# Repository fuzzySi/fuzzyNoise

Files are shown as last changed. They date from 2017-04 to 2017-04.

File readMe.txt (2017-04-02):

# fuzzyNoise

noise source, and sample and hold module for modular synth
designed by fuzzySynths. made by and for musicians. open source. 

Designs for a modular synth module. This fits in to a standard eurorack modular synth, running on the usual +12v/gnd/-12v rails. A reversed transistor in breakdown generates white noise, which is also filtered to pink noise. These are available as outputs, but the white noise, or an external source, feeds a sample and hold module to generate a CV signal, changing with every incoming gate signal. An internal LFO clocks this if there is no external gate, and is available as a separate out. Pots control LFO rate, and CV glide (portamento, ie the time between changes of voltage). 

Schematics are done in KiCad.

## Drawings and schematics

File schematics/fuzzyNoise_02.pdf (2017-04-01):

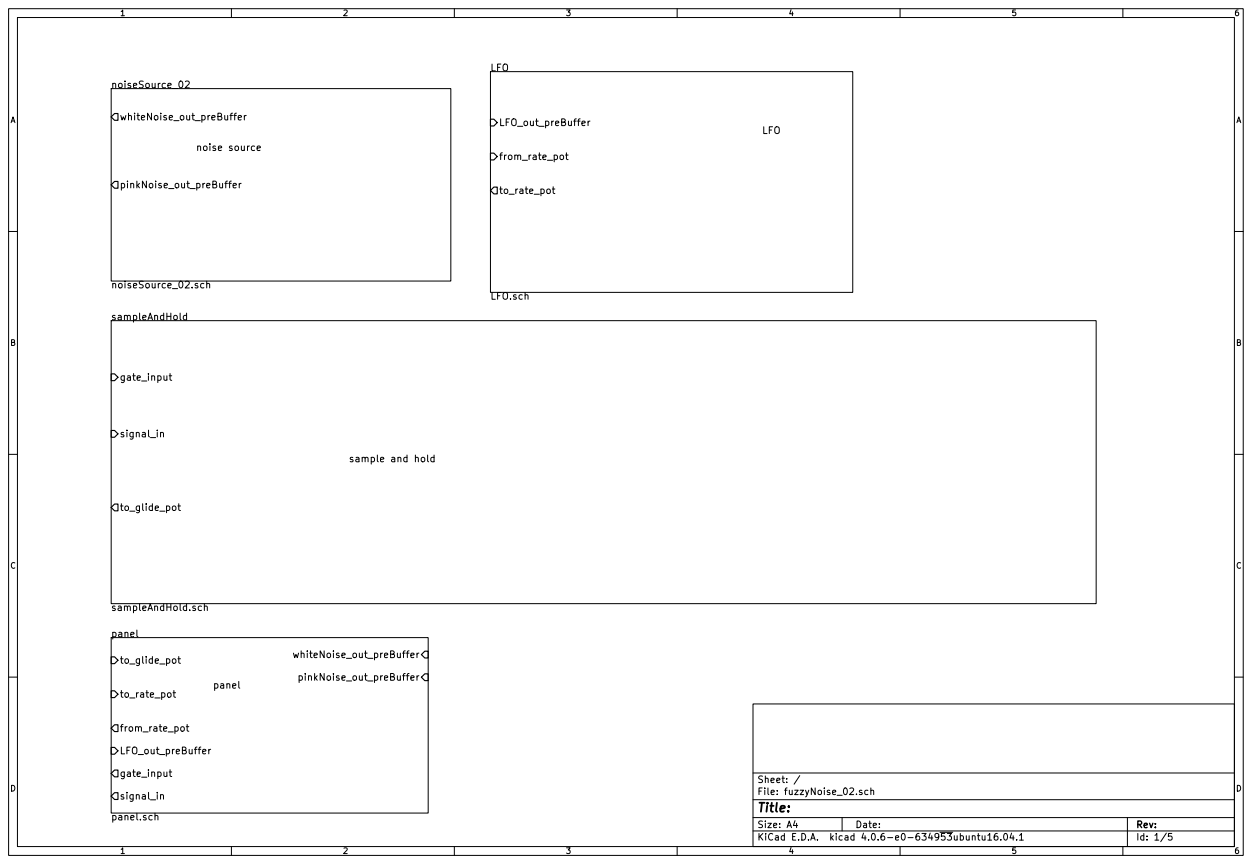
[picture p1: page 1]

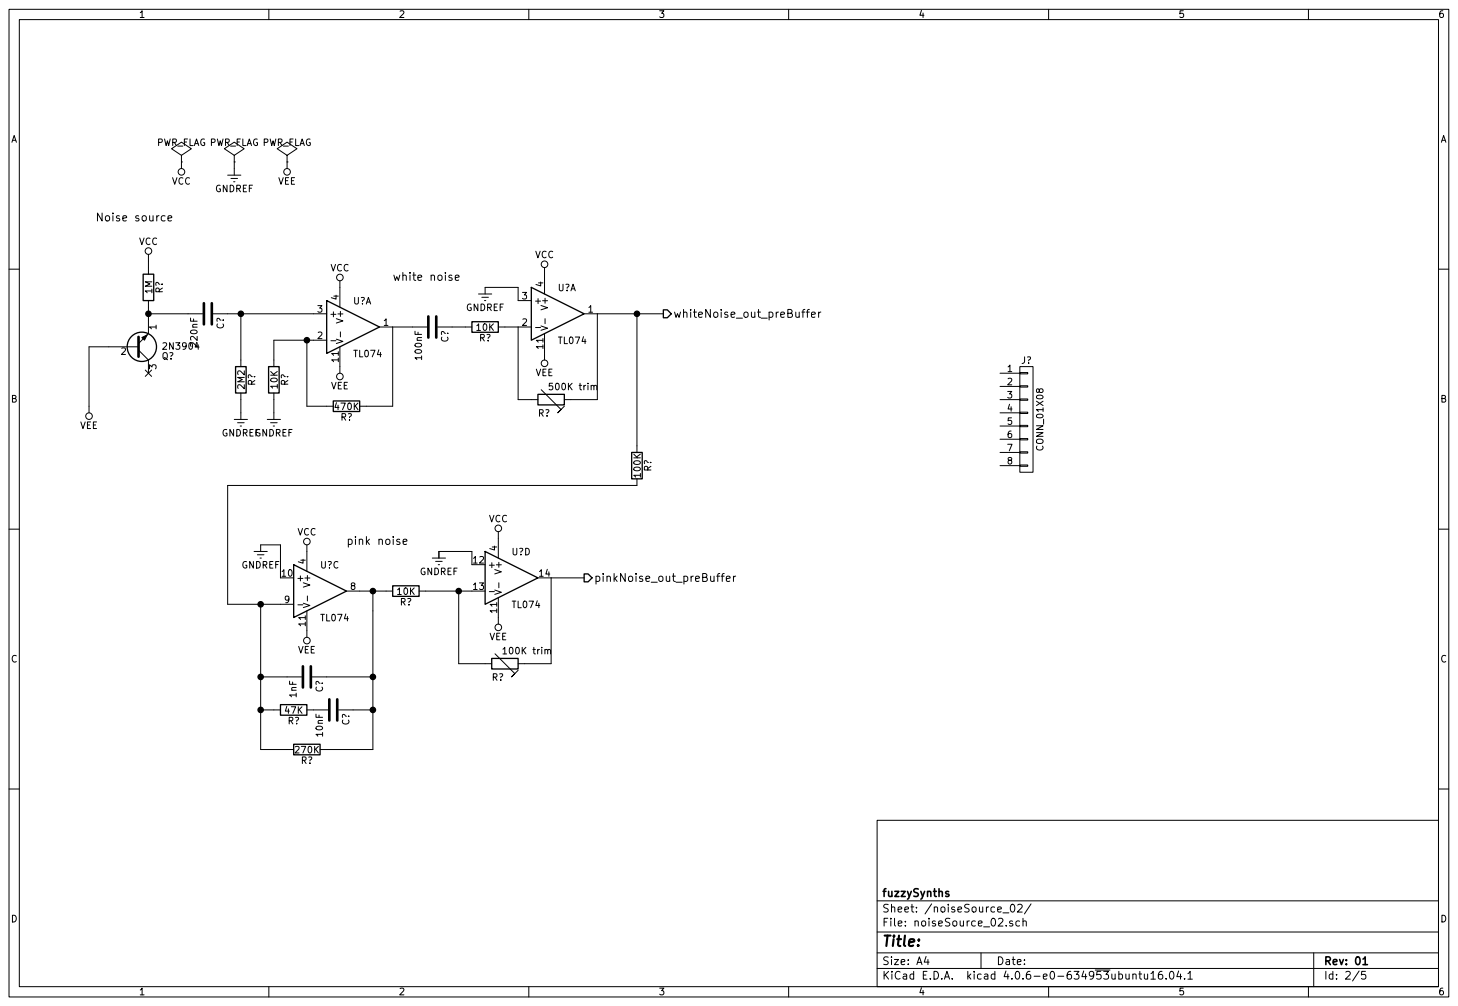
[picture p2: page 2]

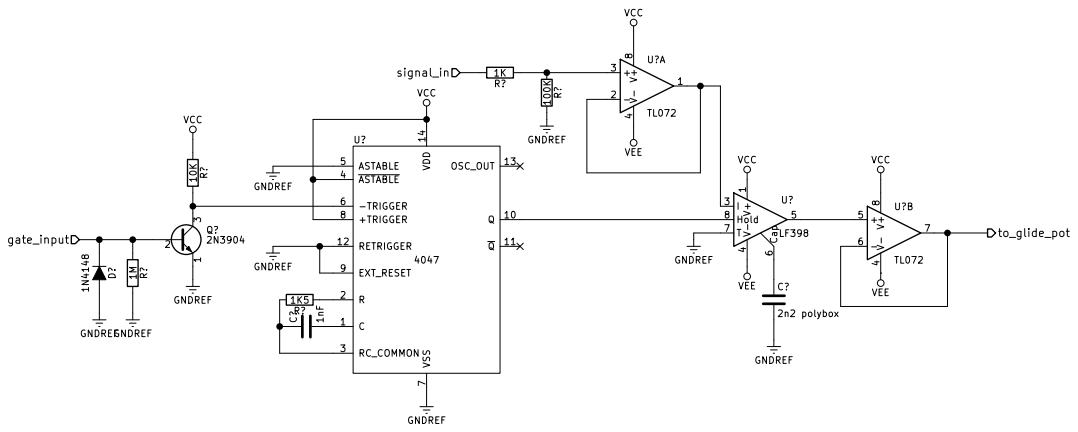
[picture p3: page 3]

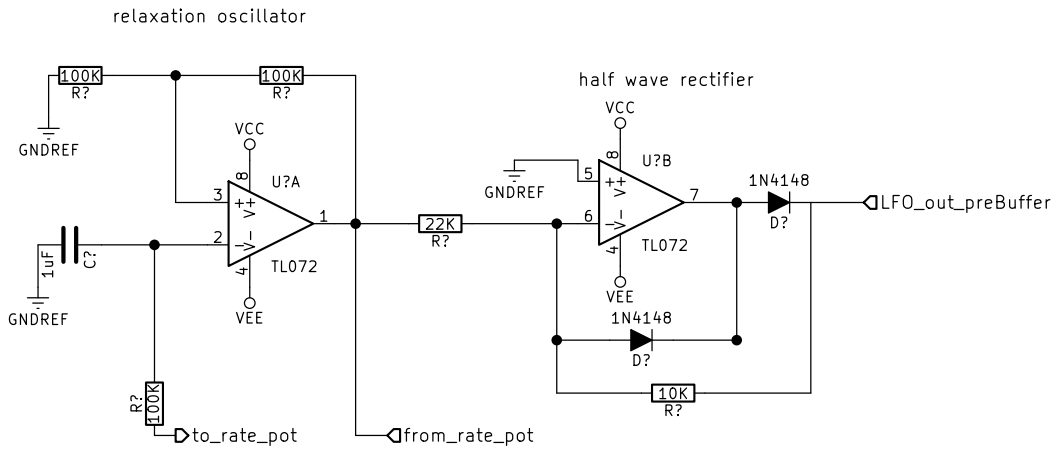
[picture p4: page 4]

Id: 4/5 Title: File: LFO.sch Sheet: /LFO/ V- 4 V+

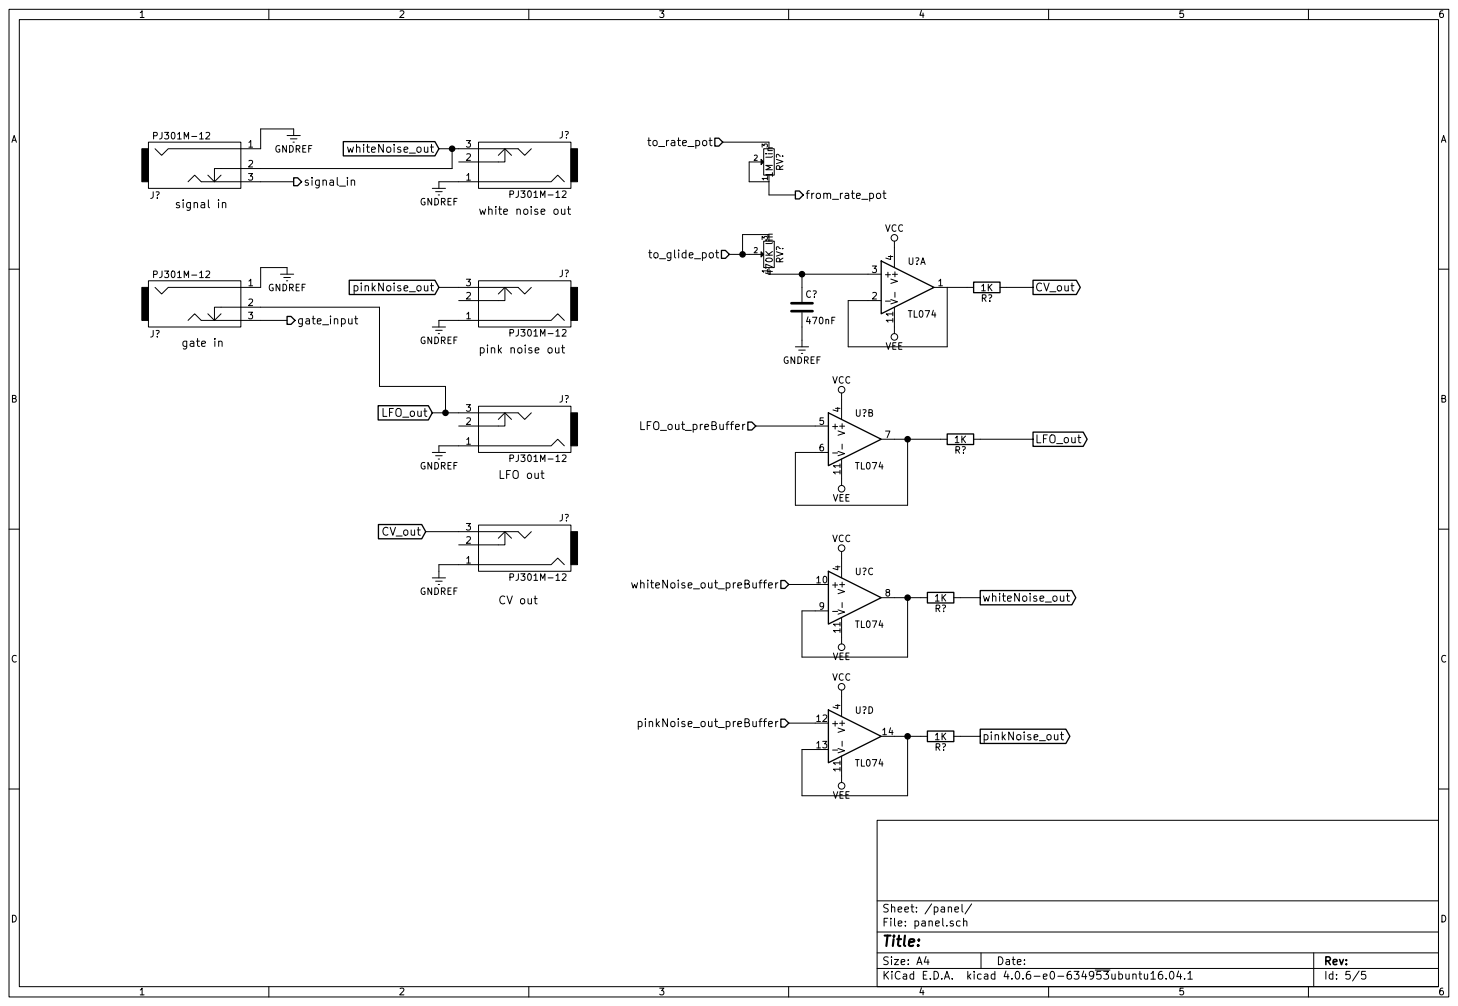
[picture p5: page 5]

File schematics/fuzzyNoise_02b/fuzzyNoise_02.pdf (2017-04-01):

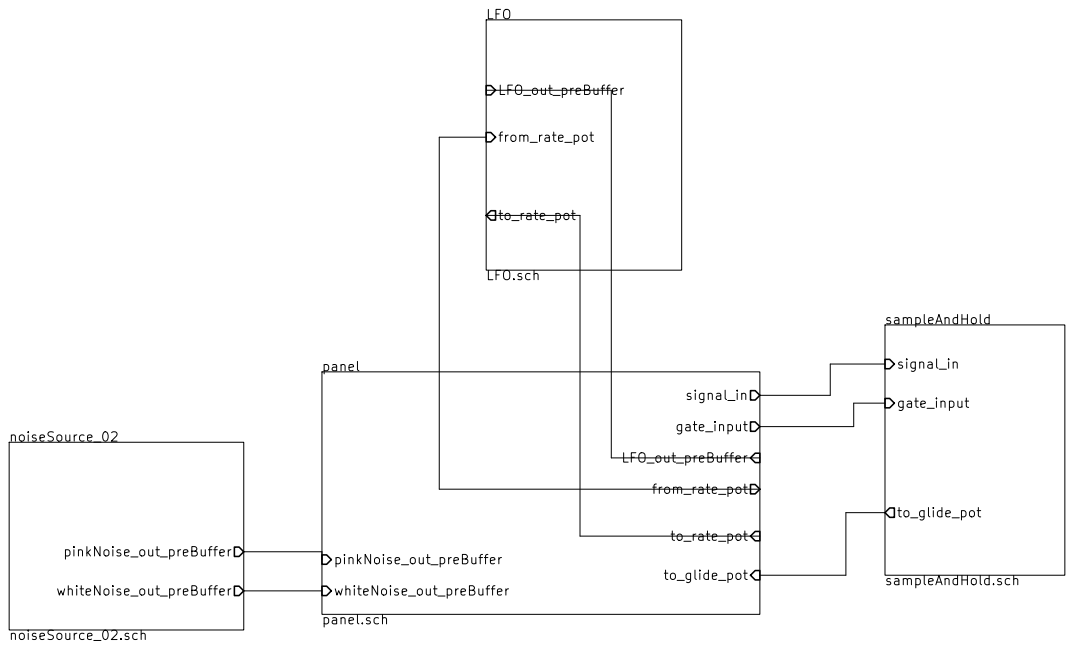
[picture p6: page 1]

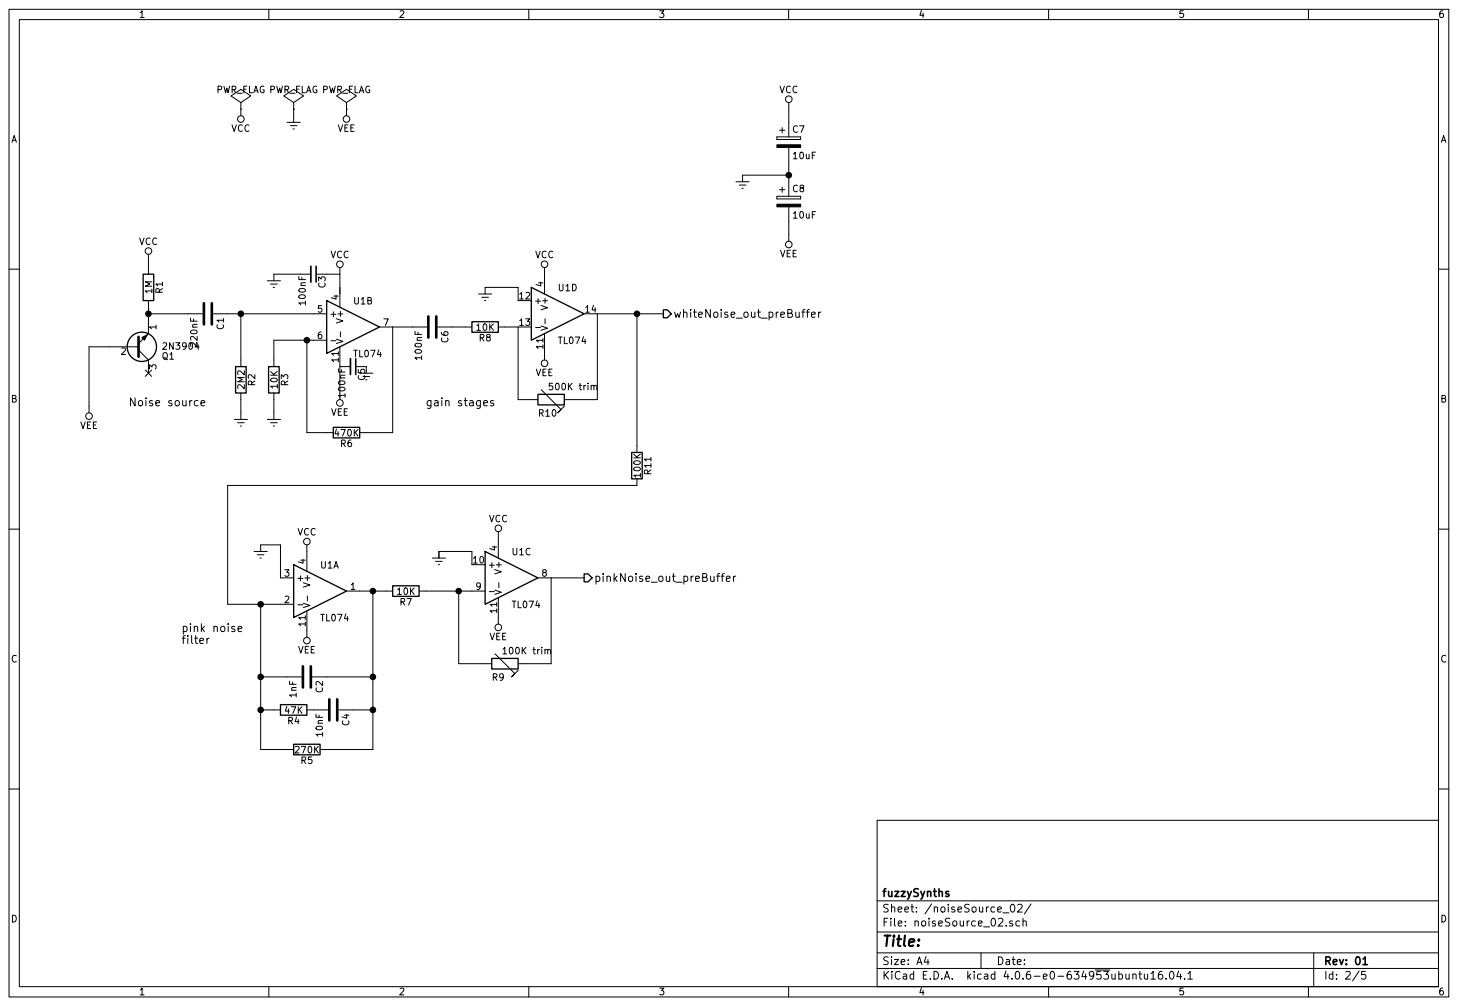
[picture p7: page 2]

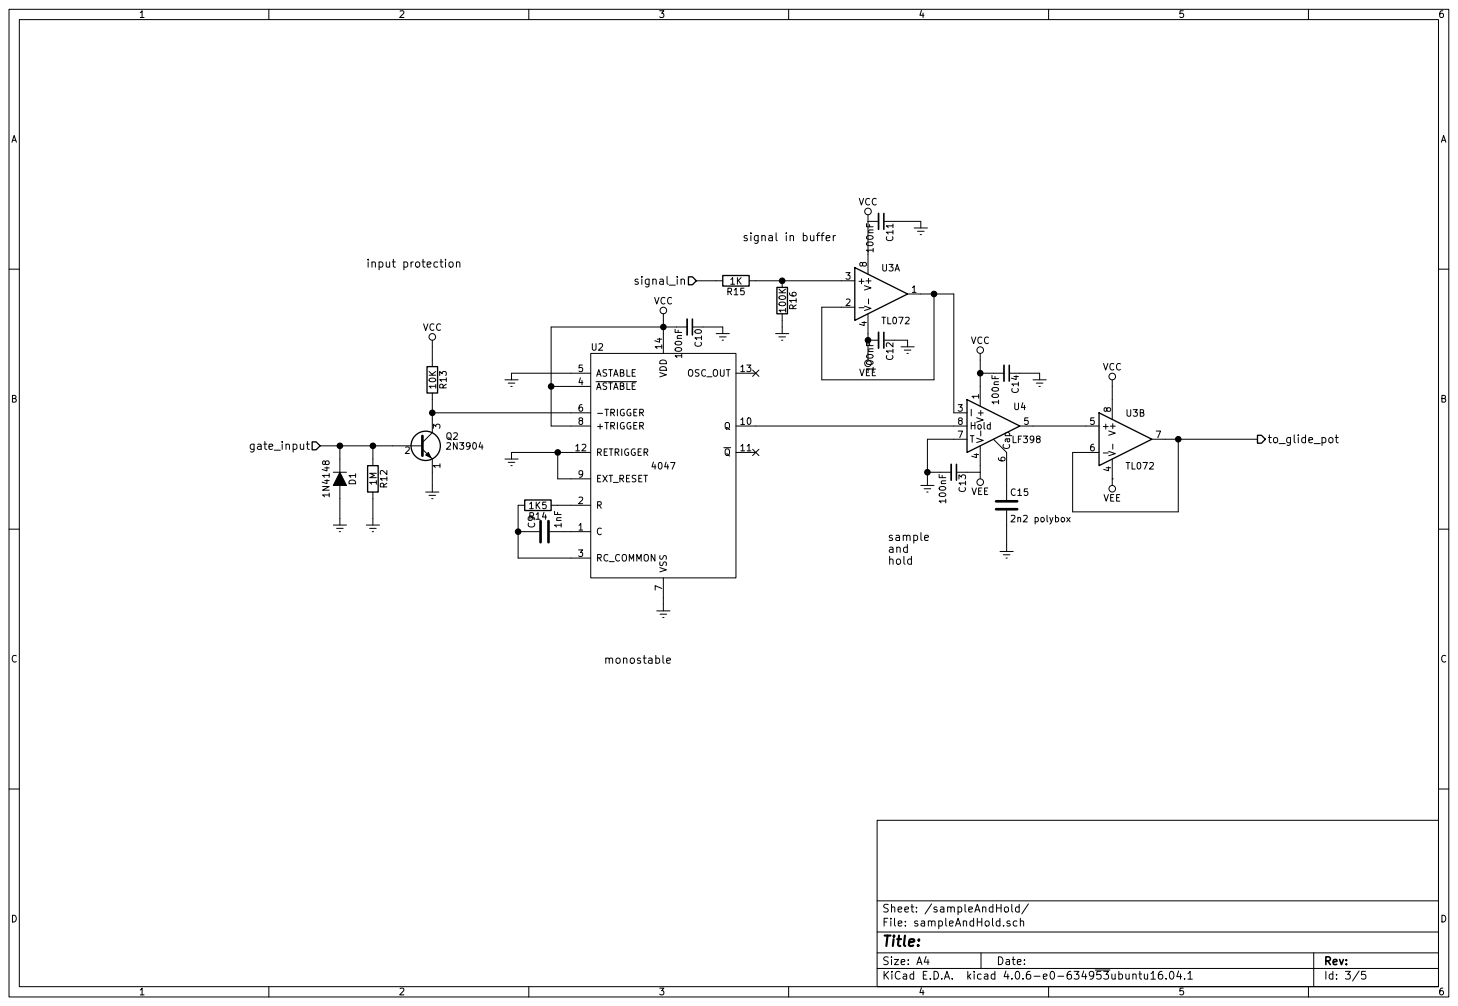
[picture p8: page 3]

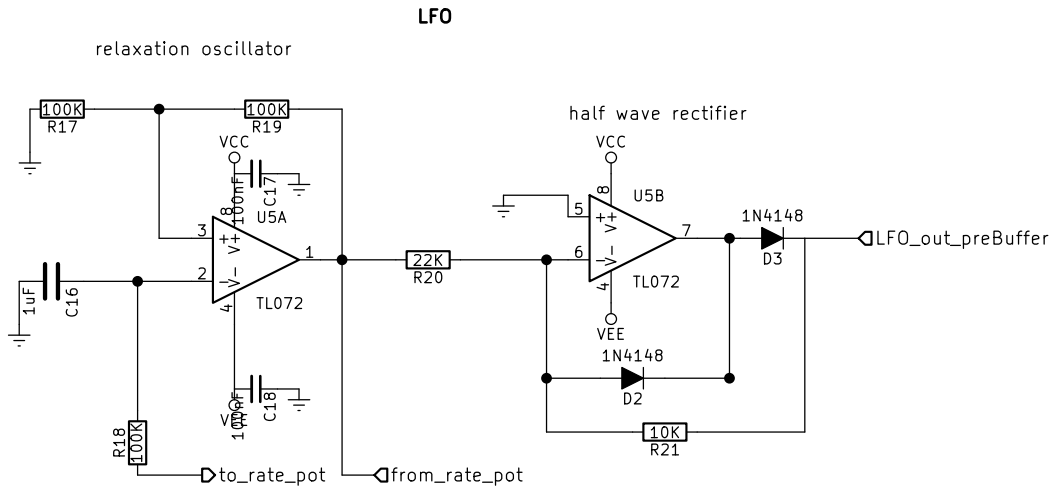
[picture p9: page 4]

Id: 4/5 Title: File: LFO.sch Sheet: /LFO/ V- 4 V+

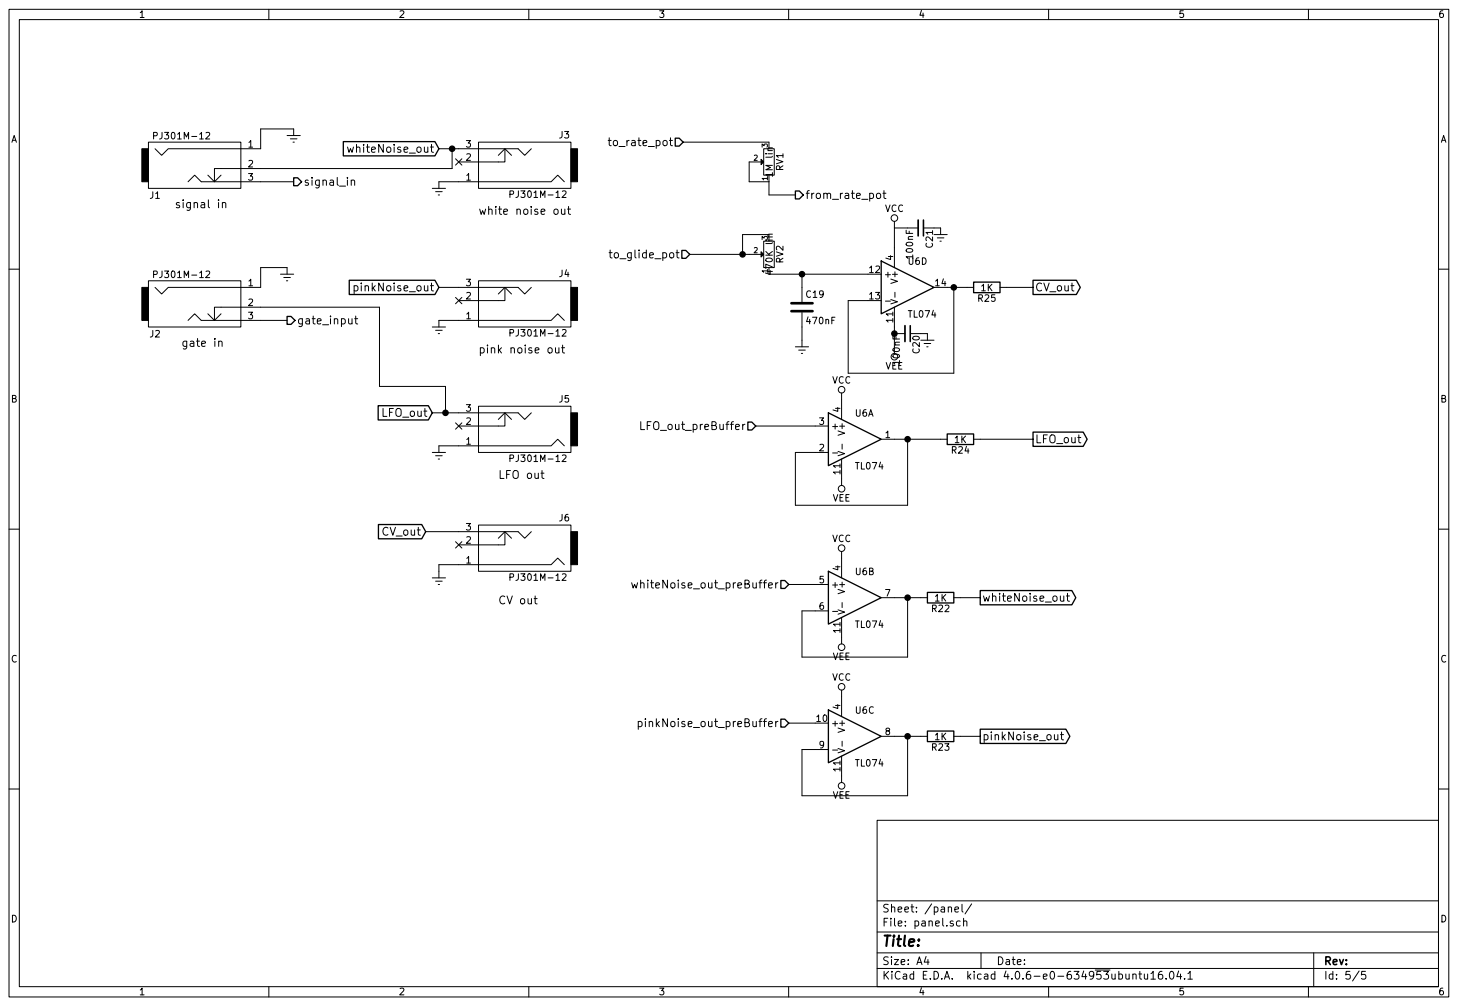
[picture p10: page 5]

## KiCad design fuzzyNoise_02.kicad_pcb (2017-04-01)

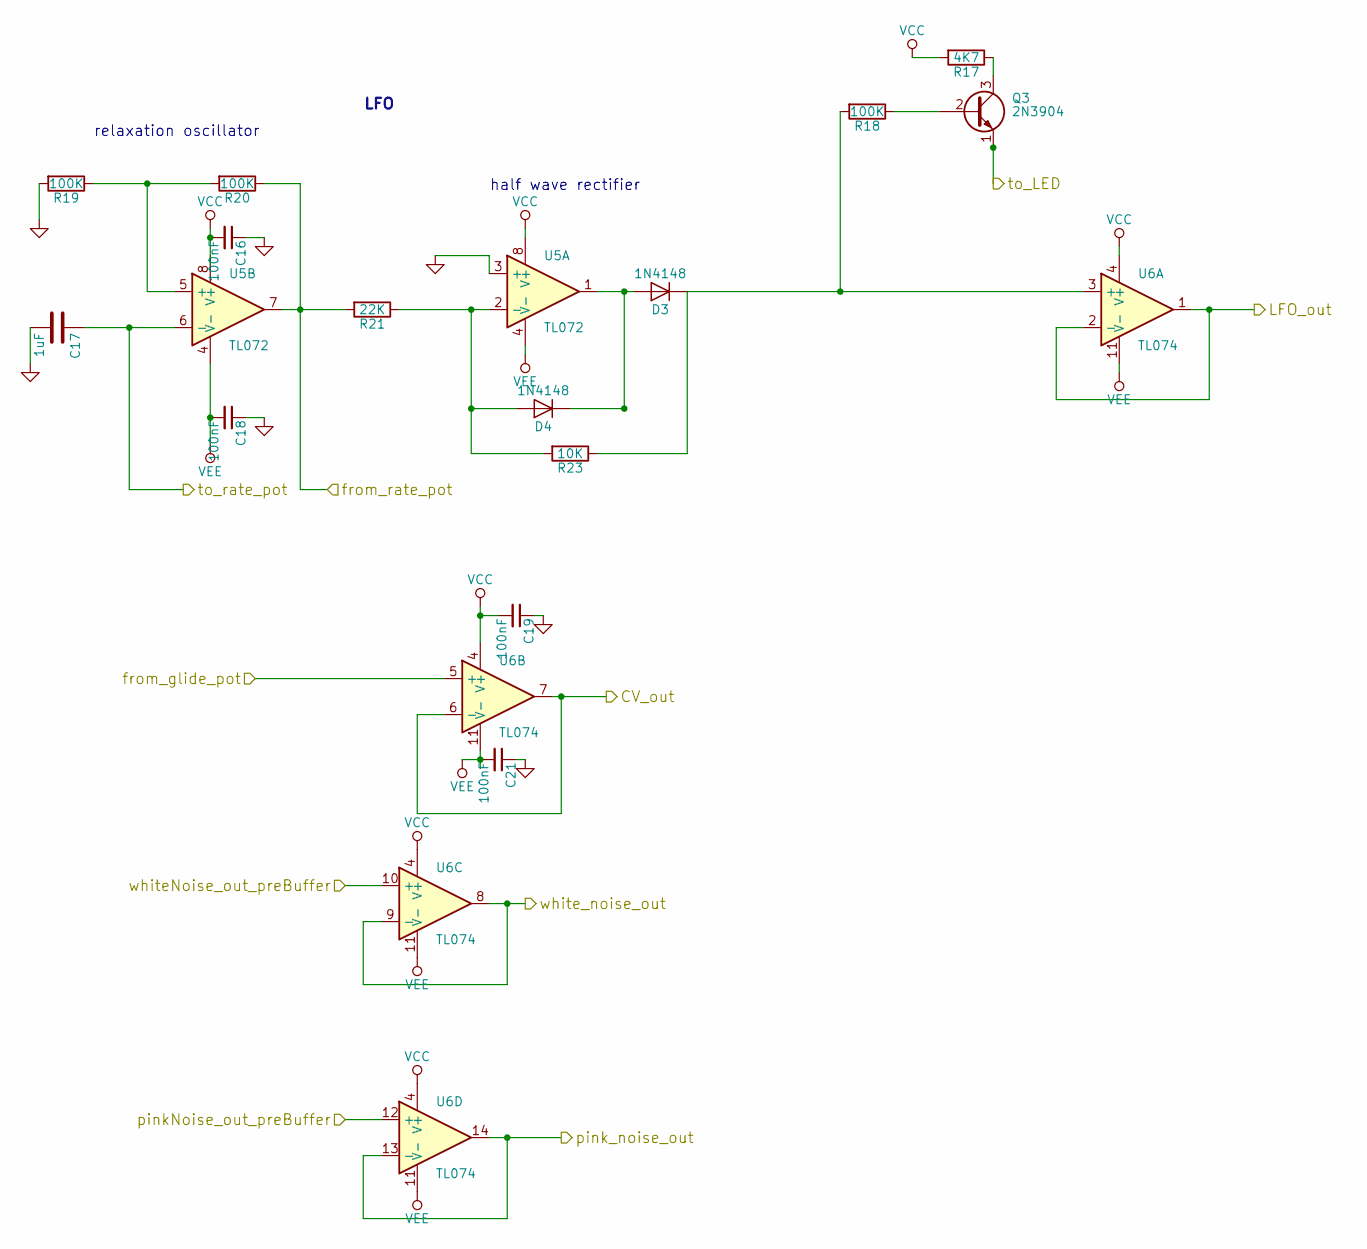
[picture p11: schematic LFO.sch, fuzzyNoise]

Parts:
C16, C18, C19, C21: 100nF; C_Disc_D3.0mm_W2.0mm_P2.50mm
C17: 1uF; C_Rect_L7.2mm_W5.5mm_P5.00mm_FKS2_FKP2_MKS2_MKP2
D3, D4: 1N4148; D_DO-41_SOD81_P7.62mm_Horizontal
Q3: 2N3904; TO-92_Molded_Narrow
R17: 4K7; R_Axial_DIN0204_L3.6mm_D1.6mm_P7.62mm_Horizontal
R18, R19, R20: 100K; R_Axial_DIN0204_L3.6mm_D1.6mm_P7.62mm_Horizontal
R21: 22K; R_Axial_DIN0204_L3.6mm_D1.6mm_P7.62mm_Horizontal
R23: 10K; R_Axial_DIN0204_L3.6mm_D1.6mm_P7.62mm_Horizontal
U5: TL072; DIP-8_W7.62mm_LongPads
U6: TL074; DIP-14_W7.62mm_LongPads

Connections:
/LFO/CV_out: U6.6 (-), U6.7; also elsewhere on the board
/LFO/LFO_out: U6.1, U6.2 (-); also elsewhere on the board
/LFO/from_glide_pot: U6.5 (+); also elsewhere on the board
/LFO/from_rate_pot: R20.1, R21.2, U5.7; also elsewhere on the board
/LFO/pinkNoise_out_preBuffer: U6.12 (+); also elsewhere on the board
/LFO/pink_noise_out: U6.13 (-), U6.14; also elsewhere on the board
/LFO/to_LED: Q3.1 (E); also elsewhere on the board
/LFO/to_rate_pot: C17.1, U5.6 (-); also elsewhere on the board
/LFO/whiteNoise_out_preBuffer: U6.10 (+); also elsewhere on the board
/LFO/white_noise_out: U6.8, U6.9 (-); also elsewhere on the board
GND: C16.1, C17.2, C18.1, C19.1, C21.1, R19.2, U5.3 (+); also elsewhere on the board
unnamed: D3.1 (K), R18.2, R23.1, U6.3 (+)
unnamed: D3.2 (A), D4.1 (K), U5.1
unnamed: D4.2 (A), R21.1, R23.2, U5.2 (-)
unnamed: Q3.2 (B), R18.1
unnamed: Q3.3 (C), R17.1
unnamed: R19.1, R20.2, U5.5 (+)
VCC: C16.2, C19.2, R17.2, U5.8 (V+), U6.4 (V+); also elsewhere on the board
VEE: C18.2, C21.2, U5.4 (V-), U6.11 (V-); also elsewhere on the board

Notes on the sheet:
relaxation oscillator
half wave rectifier
LFO

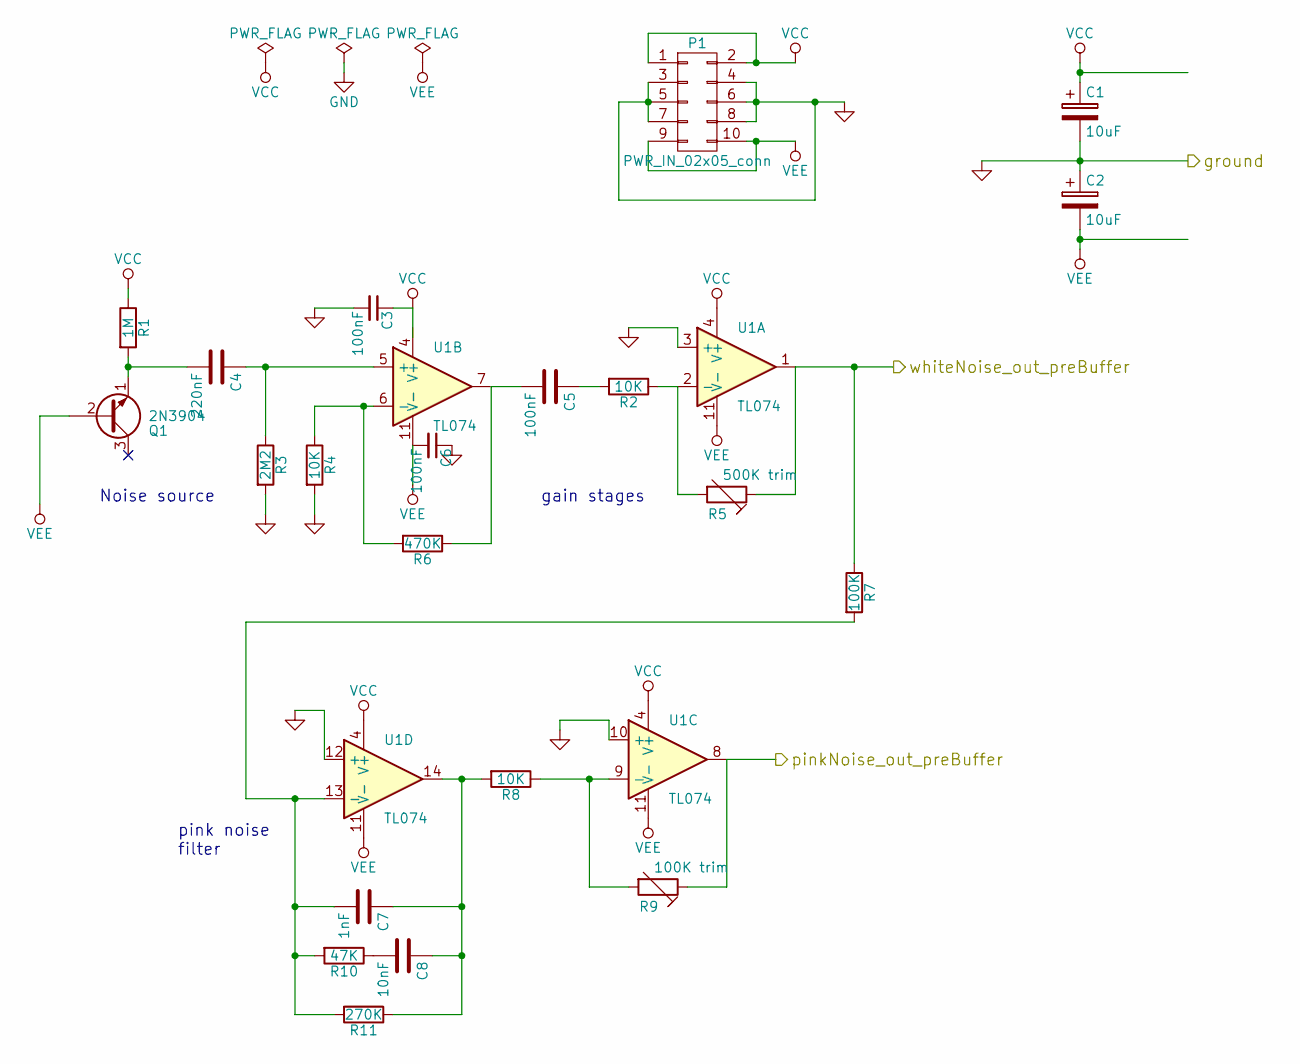
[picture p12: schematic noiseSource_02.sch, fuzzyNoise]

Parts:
C1, C2: 10uF; CP_Radial_D5.0mm_P2.50mm
C3, C5, C6: 100nF; C_Disc_D3.0mm_W2.0mm_P2.50mm
C4: 220nF; C_Disc_D3.0mm_W2.0mm_P2.50mm
C7: 1nF; C_Disc_D3.0mm_W2.0mm_P2.50mm
C8: 10nF; C_Rect_L7.2mm_W2.5mm_P5.00mm_FKS2_FKP2_MKS2_MKP2
P1: PWR_IN_02x05_conn; Pin_Header_Angled_2x05_Pitch2.54mm
Q1: 2N3904; TO-92_Molded_Narrow
R1: 1M; R_Axial_DIN0204_L3.6mm_D1.6mm_P5.08mm_Horizontal
R2, R4, R8: 10K; R_Axial_DIN0204_L3.6mm_D1.6mm_P5.08mm_Horizontal
R3: 2M2; R_Axial_DIN0204_L3.6mm_D1.6mm_P5.08mm_Horizontal
R5: 500K trim; Potentiometer_Trimmer_ACP_CA6h_Vertical
R6: 470K; R_Axial_DIN0204_L3.6mm_D1.6mm_P5.08mm_Horizontal
R7: 100K; R_Axial_DIN0204_L3.6mm_D1.6mm_P7.62mm_Horizontal
R9: 100K trim; Potentiometer_Trimmer_ACP_CA6h_Vertical
R10: 47K; R_Axial_DIN0204_L3.6mm_D1.6mm_P7.62mm_Horizontal
R11: 270K; R_Axial_DIN0204_L3.6mm_D1.6mm_P7.62mm_Horizontal
U1: TL074; DIP-14_W7.62mm_LongPads

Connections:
/LFO/pinkNoise_out_preBuffer: R9.1, U1.8; also elsewhere on the board
/LFO/whiteNoise_out_preBuffer: R5.1, R7.1, U1.1; also elsewhere on the board
GND: C1.2, C2.1, C3.2, C6.1, P1.3, P1.4, P1.5, P1.6, P1.7, P1.8, R3.2, R4.2, U1.3 (+), U1.10 (+), U1.12 (+); also elsewhere on the board
unnamed: C4.1, R3.1, U1.5 (+)
unnamed: C4.2, Q1.1 (E), R1.2
unnamed: C5.1, R2.2
unnamed: C5.2, R6.1, U1.7
unnamed: C7.1, C8.1, R8.2, R11.1, U1.14
unnamed: C7.2, R7.2, R10.2, R11.2, U1.13 (-)
unnamed: C8.2, R10.1
unnamed: R2.1, R5.2, U1.2 (-)
unnamed: R4.1, R6.2, U1.6 (-)
unnamed: R8.1, R9.2, U1.9 (-)
VCC: C1.1, C3.1, P1.1, P1.2, R1.1, U1.4 (V+); also elsewhere on the board
VEE: C2.2, C6.2, P1.9, P1.10, Q1.2 (B), U1.11 (V-); also elsewhere on the board

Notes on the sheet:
Noise source
pink noise filter
gain stages

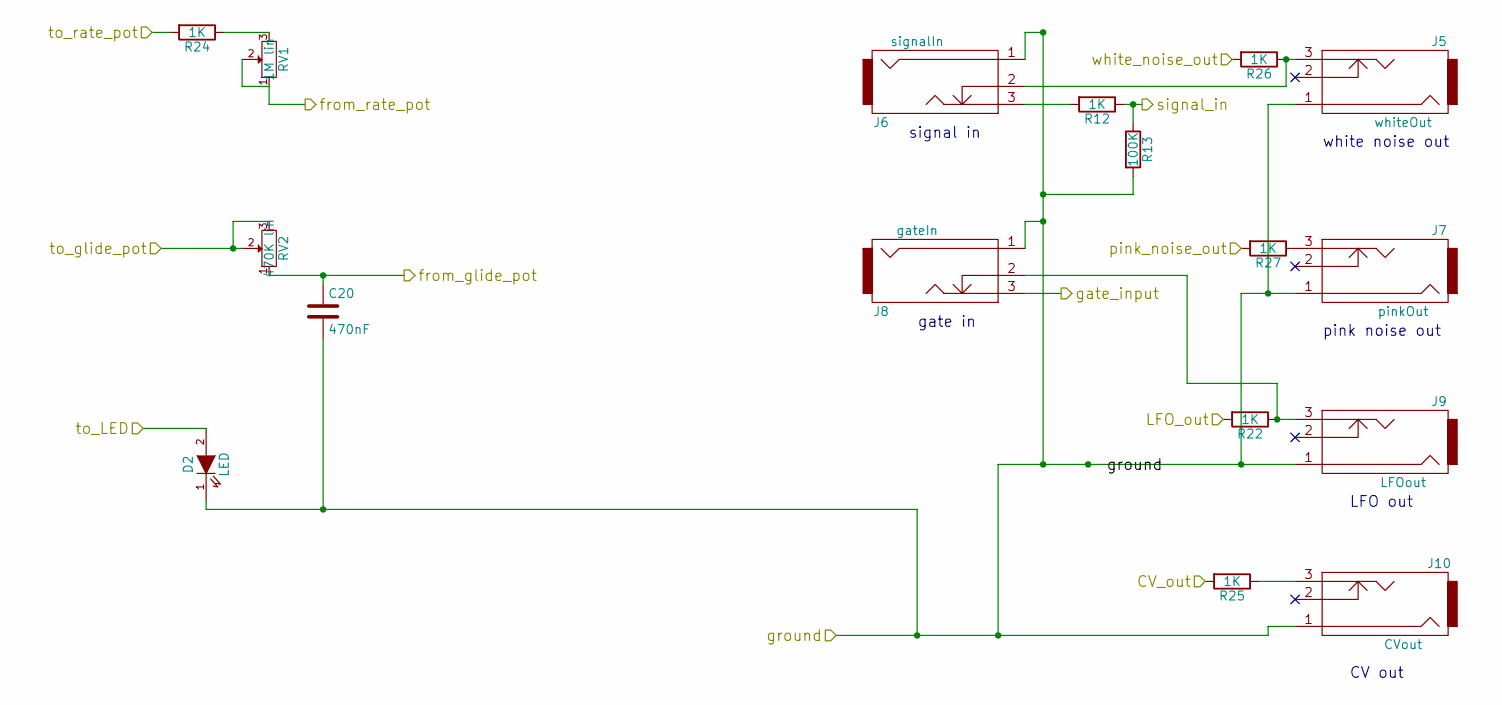
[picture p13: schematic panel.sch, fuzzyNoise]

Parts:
C20: 470nF; C_Disc_D5.0mm_W2.5mm_P5.00mm
D2: LED; LED_D3.0mm
J5: whiteOut; Thonkiconn
J6: signalIn; Thonkiconn
J7: pinkOut; Thonkiconn
J8: gateIn; Thonkiconn
J9: LFOout; Thonkiconn
J10: CVout; Thonkiconn
R12, R22, R24, R25, R26, R27: 1K; R_Axial_DIN0204_L3.6mm_D1.6mm_P7.62mm_Horizontal
R13: 100K; R_Axial_DIN0204_L3.6mm_D1.6mm_P7.62mm_Horizontal
RV1: 1M lin; Potentiometer_Alps_RK09K_Horizontal
RV2: 470K lin; Potentiometer_Alps_RK09K_Horizontal

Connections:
/panel/CV_out: R25.2; also elsewhere on the board
/panel/LFO_out: R22.2; also elsewhere on the board
/panel/from_glide_pot: C20.1, RV2.1; also elsewhere on the board
/panel/from_rate_pot: RV1.1, RV1.2; also elsewhere on the board
/panel/gate_input: J8.3; also elsewhere on the board
/panel/ground: C20.2, D2.1 (K), J5.1, J6.1, J7.1, J8.1, J9.1, J10.1, R13.2; also elsewhere on the board
/panel/pink_noise_out: R27.2; also elsewhere on the board
/panel/signal_in: R12.1, R13.1; also elsewhere on the board
/panel/to_LED: D2.2 (A); also elsewhere on the board
/panel/to_glide_pot: RV2.2, RV2.3; also elsewhere on the board
/panel/to_rate_pot: R24.2; also elsewhere on the board
/panel/white_noise_out: R26.2; also elsewhere on the board
unnamed: J5.3, J6.2, R26.1
unnamed: J6.3, R12.2
unnamed: J7.3, R27.1
unnamed: J8.2, J9.3, R22.1
unnamed: J10.3, R25.1
unnamed: R24.1, RV1.3

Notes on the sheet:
signal in
gate in
white noise out
pink noise out
LFO out
CV out

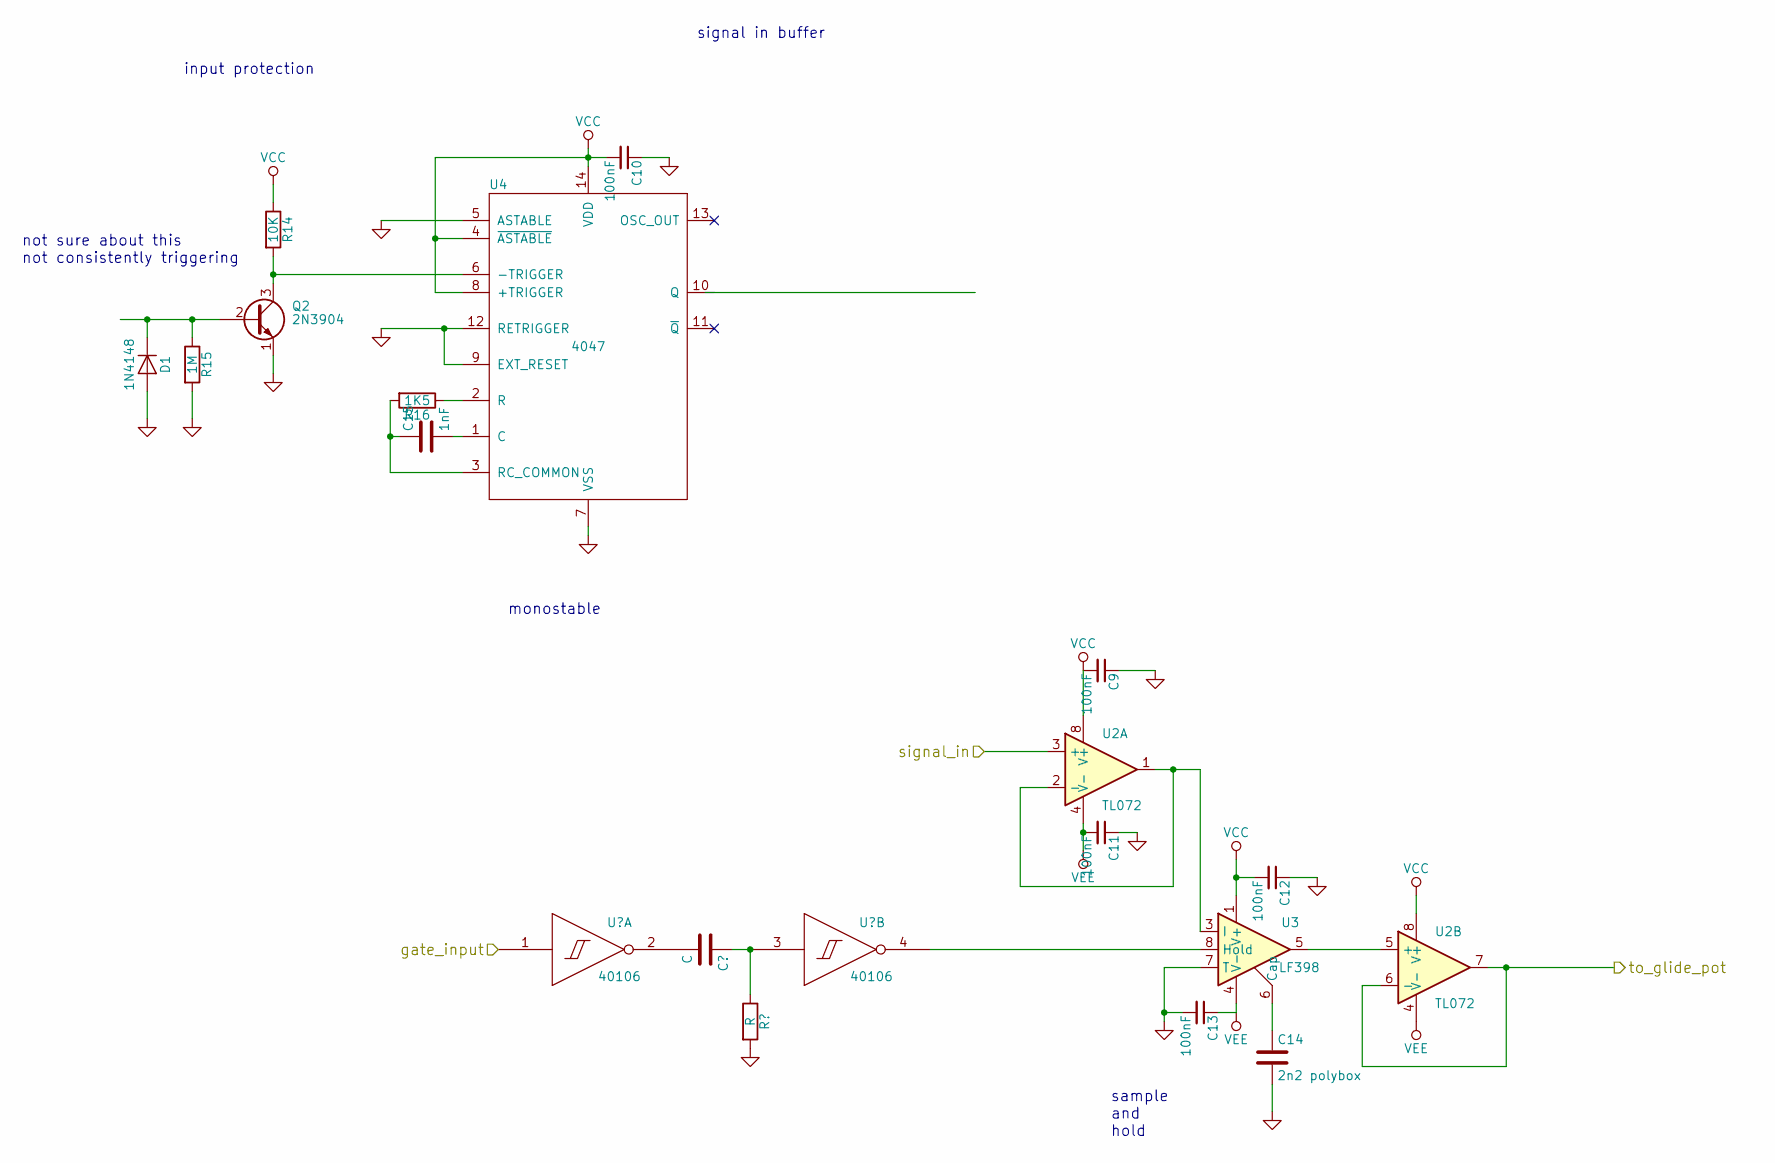
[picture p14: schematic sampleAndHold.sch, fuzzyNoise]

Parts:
C9, C10, C11, C12, C13: 100nF; C_Disc_D3.0mm_W2.0mm_P2.50mm
C14: 2n2 polybox; C_Rect_L7.2mm_W2.5mm_P5.00mm_FKS2_FKP2_MKS2_MKP2
C15: 1nF; C_Rect_L7.2mm_W2.5mm_P5.00mm_FKS2_FKP2_MKS2_MKP2
D1: 1N4148; D_DO-41_SOD81_P7.62mm_Horizontal
Q2: 2N3904; TO-92_Molded_Narrow
R14: 10K; R_Axial_DIN0204_L3.6mm_D1.6mm_P7.62mm_Horizontal
R15: 1M; R_Axial_DIN0204_L3.6mm_D1.6mm_P7.62mm_Horizontal
R16: 1K5; R_Axial_DIN0204_L3.6mm_D1.6mm_P7.62mm_Horizontal
U2: TL072; DIP-8_W7.62mm_LongPads
U3: LF398; DIP-8_W7.62mm_LongPads
U4: 4047; DIP-14_W7.62mm_LongPads

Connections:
/sampleAndHold/gate_input: D1.1 (K), Q2.2 (B), R15.1; also elsewhere on the board
/sampleAndHold/signal_in: U2.3 (+); also elsewhere on the board
/sampleAndHold/to_glide_pot: U2.6 (-), U2.7; also elsewhere on the board
GND: C9.1, C10.1, C11.1, C12.1, C13.2, C14.2, D1.2 (A), Q2.1 (E), R15.2, U3.7 (T), U4.5 (ASTABLE), U4.7 (VSS), U4.9 (EXT_RESET), U4.12 (RETRIGGER); also elsewhere on the board
unnamed: C14.1, U3.6 (Cap)
unnamed: C15.1, R16.2, U4.3 (RC_COMMON)
unnamed: C15.2, U4.1 (C)
unnamed: Q2.3 (C), R14.2, U4.6 (-TRIGGER)
unnamed: R16.1, U4.2 (R)
unnamed: U2.1, U2.2 (-), U3.3 (I)
unnamed: U2.5 (+), U3.5
unnamed: U3.8 (Hold), U4.10 (Q)
VCC: C9.2, C10.2, C12.2, R14.1, U2.8 (V+), U3.1 (V+), U4.4 (~ASTABLE), U4.8 (+TRIGGER), U4.14 (VDD); also elsewhere on the board
VEE: C11.2, C13.1, U2.4 (V-), U3.4 (V-); also elsewhere on the board

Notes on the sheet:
input protection
monostable
signal in buffer
sample and hold
not sure about this not consistently triggering

Board: 2 copper layers, 74 parts (9 on the bottom side), 58 nets, no tracks yet.

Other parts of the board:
J1: mainTop; Pin_Header_Angled_1x06_Pitch2.54mm
J2: panelTop; Socket_Strip_Straight_1x06_Pitch2.54mm
J3: mainBase; Pin_Header_Angled_1x06_Pitch2.54mm
J4: panelBase; Socket_Strip_Straight_1x06_Pitch2.54mm

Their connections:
/LFO/CV_out: J3.6; also elsewhere on the board
/LFO/LFO_out: J3.1; also elsewhere on the board
/LFO/from_glide_pot: J1.2; also elsewhere on the board
/LFO/from_rate_pot: J1.4; also elsewhere on the board
/LFO/pink_noise_out: J3.2; also elsewhere on the board
/LFO/to_LED: J1.6; also elsewhere on the board
/LFO/to_rate_pot: J1.5; also elsewhere on the board
/LFO/white_noise_out: J3.4; also elsewhere on the board
/panel/CV_out: J4.6; also elsewhere on the board
/panel/LFO_out: J4.1; also elsewhere on the board
/panel/from_glide_pot: J2.2; also elsewhere on the board
/panel/from_rate_pot: J2.4; also elsewhere on the board
/panel/gate_input: J4.3; also elsewhere on the board
/panel/ground: J2.1; also elsewhere on the board
/panel/pink_noise_out: J4.2; also elsewhere on the board
/panel/signal_in: J4.5; also elsewhere on the board
/panel/to_LED: J2.6; also elsewhere on the board
/panel/to_glide_pot: J2.3; also elsewhere on the board
/panel/to_rate_pot: J2.5; also elsewhere on the board
/panel/white_noise_out: J4.4; also elsewhere on the board
/sampleAndHold/gate_input: J3.3; also elsewhere on the board
/sampleAndHold/signal_in: J3.5; also elsewhere on the board
/sampleAndHold/to_glide_pot: J1.3; also elsewhere on the board
GND: J1.1; also elsewhere on the board

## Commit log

2017-04-01 TL072 LFO, schmitt monostable
    [fuzzyNoise_02.sch]
2017-04-01 v1, 072 relaxation oscillator, 4047 still in place
    [LFO.sch, noiseSource_02.sch, panel.sch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]
2017-04-02 changed to 40106 osc and one shot, but input schmitt not working
    [LFO.sch, sampleAndHold.sch]
